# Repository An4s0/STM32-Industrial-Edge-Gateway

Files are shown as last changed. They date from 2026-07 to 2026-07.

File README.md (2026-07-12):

# STM32 Industrial Edge Gateway

**An Ethernet-Based Environmental Monitoring System for Kunak AIR
Sensors**

An embedded industrial edge gateway built on the **STM32F767ZI** that
acquires environmental measurements from a **Kunak AIR** sensor using
**Modbus RTU over RS485**, processes the collected data, calculates the
**US Air Quality Index (AQI)**, stores historical records on an SD card,
and serves a real-time web dashboard over Ethernet.

The system operates entirely on a local network without requiring cloud
services, external APIs, or internet connectivity, making it suitable
for industrial monitoring and edge computing applications.

------------------------------------------------------------------------

# Features

-   Real-time environmental monitoring
-   Modbus RTU Master implementation over RS485
-   Ethernet-based embedded web server (LwIP HTTPD)
-   Dynamic web pages using SSI (Server Side Includes)
-   Local data logging to SD card (FATFS)
-   CSV export for historical measurements
-   US Air Quality Index (AQI) calculation
-   Live browser-based dashboard
-   Bilingual user interface (English / Arabic)
-   Automatic language switching
-   Sensor communication monitoring
-   Industrial status indication using LEDs
-   Fully offline operation (No Cloud Required)

------------------------------------------------------------------------

# System Architecture

``` text
                  +----------------------+
                  |      Kunak AIR       |
                  | Environmental Sensor |
                  +----------+-----------+
                             |
                     Modbus RTU (RS485)
                             |
                STM32 Industrial Edge Gateway
                             |
        +--------------------+--------------------+
        |                                         |
   SD Card Logging                       Embedded Web Server
        |                                         |
      FATFS                                  LwIP HTTPD
        |                                         |
        +--------------------+--------------------+
                             |
                      Ethernet Network
                             |
                     Web Browser Dashboard
```

------------------------------------------------------------------------

# System Workflow

1.  Poll the Kunak AIR sensor every **10 seconds** using Modbus RTU.
2.  Read environmental measurements.
3.  Convert raw register values into engineering units.
4.  Calculate the US AQI from PM2.5 and PM10.
5.  Store measurements on the SD card as CSV records.
6.  Update the embedded web dashboard.
7.  Serve the dashboard over the local Ethernet network.

------------------------------------------------------------------------

# Measured Parameters

-   Temperature
-   Humidity
-   Pressure
-   PM1
-   PM2.5
-   PM10
-   US AQI

------------------------------------------------------------------------

# Dashboard Features

-   Real-time environmental data
-   AQI visualization
-   Automatic data refresh
-   Local Ethernet access
-   Responsive design
-   English and Arabic interface
-   AQI status indication using EPA color categories

------------------------------------------------------------------------

# Data Logging

Example CSV record:

``` text
Timestamp,Temperature,Humidity,Pressure,PM1,PM2.5,PM10,AQI
2026-06-14 12:00:00,31.20,46.00,1012.0,12.5,18.3,25.7,72
```

------------------------------------------------------------------------

# Reliability Features

-   Modbus CRC16 verification
-   Communication timeout detection
-   Sensor offline monitoring
-   Runtime status indication using LEDs
-   Watchdog-based recovery support
-   Local data storage without internet dependency

------------------------------------------------------------------------

# Technologies Used

-   Embedded Systems
-   Industrial IoT (IIoT)
-   Edge Computing
-   STM32
-   Modbus RTU
-   RS485
-   Ethernet
-   LwIP
-   FATFS
-   Embedded Web Server
-   Data Logging

------------------------------------------------------------------------

<br/>

**Keep building. Keep learning.**

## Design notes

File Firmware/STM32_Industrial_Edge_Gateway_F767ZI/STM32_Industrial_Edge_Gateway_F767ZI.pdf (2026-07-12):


06/07/2026

Industrial_Edge_Monitoring_System Project Configuration Report

## 1. Description

### 1.1. Project

Project Name | Industrial_Edge_Monitoring_System
Board Name | NUCLEO-F767ZI
Generated with: | STM32CubeMX 6.18.0
Date | 07/06/2026

### 1.2. MCU

MCU Series | STM32F7
MCU Line | STM32F7x7
MCU name | STM32F767ZITx
MCU Package | LQFP144
MCU Pin number | 144

### 1.3. Core(s) information

Core(s) | Arm Cortex-M7
1.4. Caution

The report was generated although the configuration was in a modified state. It may be not accurate

## 2. Pinout Configuration

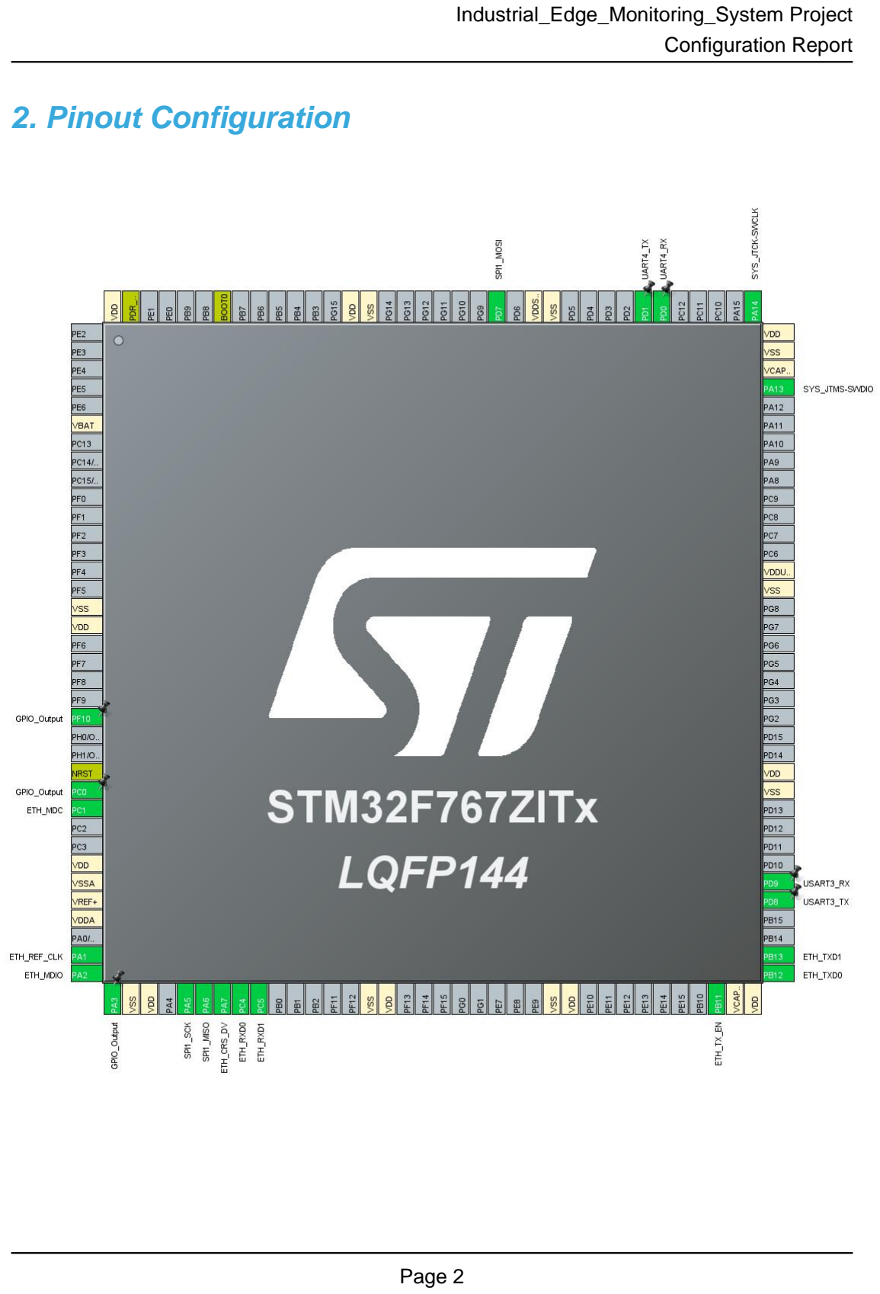
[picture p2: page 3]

## 3. Pins Configuration

Pin Number LQFP144 | Pin Name (function after reset) | Pin Type | Alternate Function(s) | Label
6 | VBAT | Power
16 | VSS | Power
17 | VDD | Power
22 | PF10 * | I/O | GPIO_Output
25 | NRST | Reset
26 | PC0 * | I/O | GPIO_Output
27 | PC1 | I/O | ETH_MDC
30 | VDD | Power
31 | VSSA | Power
32 | VREF+ | Power
33 | VDDA | Power
35 | PA1 | I/O | ETH_REF_CLK
36 | PA2 | I/O | ETH_MDIO
37 | PA3 * | I/O | GPIO_Output
38 | VSS | Power
39 | VDD | Power
41 | PA5 | I/O | SPI1_SCK
42 | PA6 | I/O | SPI1_MISO
43 | PA7 | I/O | ETH_CRS_DV
44 | PC4 | I/O | ETH_RXD0
45 | PC5 | I/O | ETH_RXD1
51 | VSS | Power
52 | VDD | Power
61 | VSS | Power
62 | VDD | Power
70 | PB11 | I/O | ETH_TX_EN
71 | VCAP_1 | Power
72 | VDD | Power
73 | PB12 | I/O | ETH_TXD0
74 | PB13 | I/O | ETH_TXD1
77 | PD8 | I/O | USART3_TX
78 | PD9 | I/O | USART3_RX
83 | VSS | Power
84 | VDD | Power
94 | VSS | Power
95 | VDDUSB | Power

Pin Number LQFP144 | Pin Name (function after reset) | Pin Type | Alternate Function(s) | Label
105 | PA13 | I/O | SYS_JTMS-SWDIO
106 | VCAP_2 | Power
107 | VSS | Power
108 | VDD | Power
109 | PA14 | I/O | SYS_JTCK-SWCLK
114 | PD0 | I/O | UART4_RX
115 | PD1 | I/O | UART4_TX
120 | VSS | Power
121 | VDDSDMMC | Power
123 | PD7 | I/O | SPI1_MOSI
130 | VSS | Power
131 | VDD | Power
138 | BOOT0 | Boot
143 | PDR_ON | Reset
144 | VDD | Power

* The pin is affected with an I/O function

## 4. Clock Tree Configuration

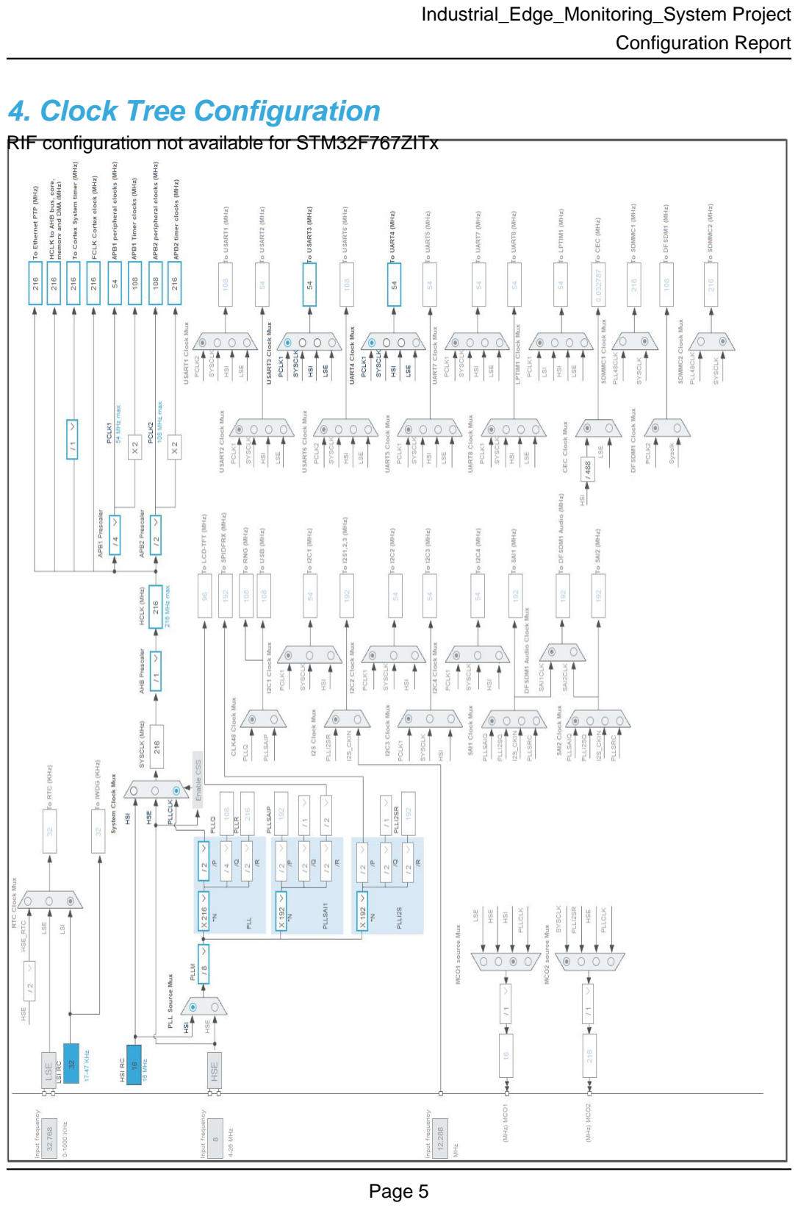
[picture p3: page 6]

RIF configuration not available for STM32F767ZITx

## 1. Power Consumption Calculator report

### 1.1. Microcontroller Selection

Series | STM32F7
Line | STM32F7x7
MCU | STM32F767ZITx
Datasheet | DS11532_Rev4

### 1.2. Parameter Selection

Temperature | 25
Vdd | 3.3

### 1.3. Battery Selection

Battery | Alkaline(9V)
Capacity | 625.0 mAh
Self Discharge | 0.3 %/month
Nominal Voltage | 9.0 V
Max Cont Current | 200.0 mA
Max Pulse Current | 0.0 mA
Cells in series | 1
Cells in parallel | 1

### 1.4. Sequence

Step | Step1 | Step2
Mode | RUN | STOP_UDM (Under Drive)
Vdd | 3.3 | 3.3
Voltage Source | Battery | Battery
Range | Scale1-High | No Scale
Fetch Type | ICTM FLASH-SingleBank REGON | n/a
CPU Frequency | 216 MHz | 0 Hz
Clock Configuration | HSE PLL | Regulator_LP Flash-PwrDwn
Clock Source Frequency | 4 MHz | 0 Hz
Peripherals
Additional Cons. | 0 mA | 0 mA
Average Current | 118 mA | 130 µA
Duration | 0.1 ms | 0.9 ms
DMIPS | 462.0 | 0.0
Ta Max | 89.42 | 104.98
Category | In DS Table | In DS Table

### 1.5. Results

Sequence Time | 1 ms | Average Current | 11.92 mA
Battery Life | 2 days, 4 hours | Average DMIPS | 462.24005 DMIPS

### 1.6. Chart

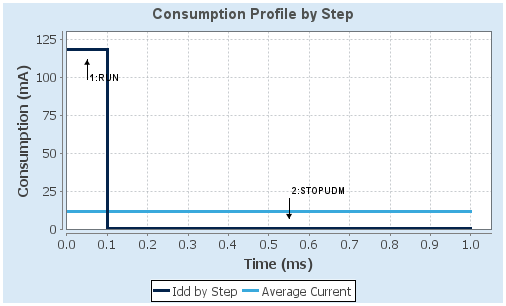
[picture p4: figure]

## 2. Software Project

### 2.1. Project Settings

Name | Value
Project Name | Industrial_Edge_Monitoring_System
Project Folder | D:\Industrial_Edge_Monitoring_System
Toolchain / IDE | CMake
Firmware Package Name and Version | STM32Cube FW_F7 V1.17.4
Application Structure | Advanced
Generate Under Root | No
Do not generate the main() | No
Minimum Heap Size | 0x200
Minimum Stack Size | 0x400

### 2.2. Code Generation Settings

Name | Value
STM32Cube MCU packages and embedded software | Copy only the necessary library files
Generate peripheral initialization as a pair of '.c/.h' files | No
Backup previously generated files when re-generating | No
Keep User Code when re-generating | Yes
Delete previously generated files when not re-generated | Yes
Set all free pins as analog (to optimize the power consumption) | No
Enable Full Assert | No

### 2.3. Advanced Settings - Generated Function Calls

Rank | Function Name | Peripheral Instance Name
1 | SystemClock_Config | RCC
2 | MX_GPIO_Init | GPIO
3 | MX_UART4_Init | UART4
4 | MX_USART3_UART_Init | USART3
5 | MX_SPI1_Init | SPI1
6 | MX_FATFS_Init | FATFS
7 | MX_ETH_Init | ETH

## 3. Peripherals and Middlewares Configuration

### 3.1. CORTEX_M7

3.1.1. Parameter Settings:

Speculation default mode Settings:

Speculation default mode | Enabled *
Cortex Interface Settings:
Flash Interface | AXI Interface
ART ACCELERATOR | Disabled
Instruction Prefetch | Disabled
CPU ICache | Disabled
CPU DCache | Disabled
Cortex Memory Protection Unit Control Settings:
MPU Control Mode | Background Region Privileged accesses only + MPU Disabled during hard fault, NMI and FAULTMASK handlers

Cortex Memory Protection Unit Region 0 Settings:

MPU Region | Enabled
MPU Region Base Address | 0x0 *
MPU Region Size | 4GB
MPU SubRegion Disable | 0x87 *
MPU TEX field level | level 0
MPU Access Permission | ALL ACCESS NOT PERMITTED
MPU Instruction Access | DISABLE
MPU Shareability Permission | ENABLE
MPU Cacheable Permission | DISABLE
MPU Bufferable Permission | DISABLE
Cortex Memory Protection Unit Region 1 Settings:
MPU Region | Disabled
Cortex Memory Protection Unit Region 2 Settings:
MPU Region | Disabled
Cortex Memory Protection Unit Region 3 Settings:
MPU Region | Disabled
Cortex Memory Protection Unit Region 4 Settings:
MPU Region | Disabled
Cortex Memory Protection Unit Region 5 Settings:
MPU Region | Disabled
Cortex Memory Protection Unit Region 6 Settings:
MPU Region | Disabled
Cortex Memory Protection Unit Region 7 Settings:

MPU Region | Disabled

### 3.2. ETH

Mode: RMII
3.2.1. Parameter Settings:

General : Ethernet Configuration:

Ethernet MAC Address | 00:80:E1:00:00:00
Tx Descriptor Length | 4
First Tx Descriptor Address | 0x2007c0a0 *
Rx Descriptor Length | 4
First Rx Descriptor Address | 0x2007c000 *
Rx Buffers Length | 1524
Rx Mode | Polling Mode

### 3.3. RCC

3.3.1. Parameter Settings:

System Parameters:

VDD voltage (V) | 3.3
Flash Latency(WS) | 7 WS (8 CPU cycle)
RCC Parameters:
HSI Calibration Value | 16
TIM Prescaler Selection | Disabled
HSE Startup Timout Value (ms) | 100
LSE Startup Timout Value (ms) | 5000
Power Parameters:
Power Over Drive | Enabled
Power Regulator Voltage Scale | Power Regulator Voltage Scale 1

### 3.4. SPI1

Mode: Full-Duplex Master
3.4.1. Parameter Settings:

Basic Parameters:

Frame Format | Motorola
Data Size | 8 Bits *
First Bit | MSB First
Clock Parameters:
Prescaler (for Baud Rate) | 256 *
Baud Rate | 421.875 KBits/s *
Clock Polarity (CPOL) | Low
Clock Phase (CPHA) | 1 Edge
Advanced Parameters:
CRC Calculation | Disabled
NSSP Mode | Enabled
NSS Signal Type | Software

### 3.5. SYS

Debug: Serial Wire
Timebase Source: SysTick

### 3.6. UART4

Mode: Asynchronous
3.6.1. Parameter Settings:

Basic Parameters:

Baud Rate | 19200 *
Word Length | 8 Bits (including Parity)
Parity | None
Stop Bits | 1
Advanced Parameters:
Data Direction | Receive and Transmit
Over Sampling | 16 Samples
Single Sample | Disable
Advanced Features:
Auto Baudrate | Disable
TX Pin Active Level Inversion | Disable
RX Pin Active Level Inversion | Disable
Data Inversion | Disable
TX and RX Pins Swapping | Disable
Overrun | Enable
DMA on RX Error | Enable

MSB First | Disable

### 3.7. USART3

Mode: Asynchronous
3.7.1. Parameter Settings:

Basic Parameters:

Baud Rate | 115200
Word Length | 8 Bits (including Parity)
Parity | None
Stop Bits | 1
Advanced Parameters:
Data Direction | Receive and Transmit
Over Sampling | 16 Samples
Single Sample | Disable
Advanced Features:
Auto Baudrate | Disable
TX Pin Active Level Inversion | Disable
RX Pin Active Level Inversion | Disable
Data Inversion | Disable
TX and RX Pins Swapping | Disable
Overrun | Enable
DMA on RX Error | Enable
MSB First | Disable

### 3.8. FATFS

mode: User-defined
3.8.1. Set Defines:

Version:

FATFS version | R0.12c
Function Parameters:
FS_READONLY (Read-only mode) | Disabled
FS_MINIMIZE (Minimization level) | Disabled
USE_STRFUNC (String functions) | Enabled with LF -> CRLF conversion
USE_FIND (Find functions) | Disabled
USE_MKFS (Make filesystem function) | Enabled
USE_FASTSEEK (Fast seek function) | Enabled

USE_EXPAND (Use f_expand function) | Disabled
USE_CHMOD (Change attributes function) | Disabled
USE_LABEL (Volume label functions) | Disabled
USE_FORWARD (Forward function) | Disabled
Locale and Namespace Parameters:
CODE_PAGE (Code page on target) | Latin 1
USE_LFN (Use Long Filename) | Disabled
MAX_LFN (Max Long Filename) | 255
LFN_UNICODE (Enable Unicode) | ANSI/OEM
STRF_ENCODE (Character encoding) | UTF-8
FS_RPATH (Relative Path) | Disabled
Physical Drive Parameters:
VOLUMES (Logical drives) | 1
MAX_SS (Maximum Sector Size) | 512
MIN_SS (Minimum Sector Size) | 512
MULTI_PARTITION (Volume partitions feature) | Disabled
USE_TRIM (Erase feature) | Disabled
FS_NOFSINFO (Force full FAT scan) | 0
System Parameters:
FS_TINY (Tiny mode) | Disabled
FS_EXFAT (Support of exFAT file system) | Disabled
FS_NORTC (Timestamp feature) | Dynamic timestamp
FS_REENTRANT (Re-Entrancy) | Disabled
FS_TIMEOUT (Timeout ticks) | 1000
FS_LOCK (Number of files opened simultaneously) | 2

* User modified value

## 4. System Configuration

### 4.1. GPIO configuration

IP | Pin | Signal | GPIO mode | GPIO pull/up pull down | Max Speed | User Label
ETH | PC1 | ETH_MDC | Alternate Function Push Pull | No pull-up and no pull-down | High
| PA1 | ETH_REF_CLK | Alternate Function Push Pull | No pull-up and no pull-down | High
| PA2 | ETH_MDIO | Alternate Function Push Pull | No pull-up and no pull-down | High
| PA7 | ETH_CRS_DV | Alternate Function Push Pull | No pull-up and no pull-down | High
| PC4 | ETH_RXD0 | Alternate Function Push Pull | No pull-up and no pull-down | High
| PC5 | ETH_RXD1 | Alternate Function Push Pull | No pull-up and no pull-down | High
| PB11 | ETH_TX_EN | Alternate Function Push Pull | No pull-up and no pull-down | High
| PB12 | ETH_TXD0 | Alternate Function Push Pull | No pull-up and no pull-down | High
| PB13 | ETH_TXD1 | Alternate Function Push Pull | No pull-up and no pull-down | High
SPI1 | PA5 | SPI1_SCK | Alternate Function Push Pull | No pull-up and no pull-down | Very High *
| PA6 | SPI1_MISO | Alternate Function Push Pull | No pull-up and no pull-down | Very High *
| PD7 | SPI1_MOSI | Alternate Function Push Pull | No pull-up and no pull-down | Very High *
SYS | PA13 | SYS_JTMS-SWDIO | n/a | n/a | n/a
| PA14 | SYS_JTCK-SWCLK | n/a | n/a | n/a
UART4 | PD0 | UART4_RX | Alternate Function Push Pull | No pull-up and no pull-down | Very High *
| PD1 | UART4_TX | Alternate Function Push Pull | No pull-up and no pull-down | Very High *
USART3 | PD8 | USART3_TX | Alternate Function Push Pull | No pull-up and no pull-down | Very High *
| PD9 | USART3_RX | Alternate Function Push Pull | No pull-up and no pull-down | Very High *
GPIO | PF10 | GPIO_Output | Output Push Pull | No pull-up and no pull-down | Low
| PC0 | GPIO_Output | Output Push Pull | No pull-up and no pull-down | Low
| PA3 | GPIO_Output | Output Push Pull | No pull-up and no pull-down | Low

### 4.2. DMA configuration

nothing configured in DMA service

### 4.3. NVIC configuration

4.3.1. NVIC
Interrupt Table | Enable | Preenmption Priority | SubPriority
Non maskable interrupt | true | 0 | 0
Hard fault interrupt | true | 0 | 0
Memory management fault | true | 0 | 0
Pre-fetch fault, memory access fault | true | 0 | 0
Undefined instruction or illegal state | true | 0 | 0
System service call via SWI instruction | true | 0 | 0
Debug monitor | true | 0 | 0
Pendable request for system service | true | 0 | 0
System tick timer | true | 0 | 0
PVD interrupt through EXTI line 16 | unused
Flash global interrupt | unused
RCC global interrupt | unused
SPI1 global interrupt | unused
USART3 global interrupt | unused
UART4 global interrupt | unused
Ethernet global interrupt | unused
Ethernet wake-up interrupt through EXTI line 19 | unused
FPU global interrupt | unused
4.3.2. NVIC Code generation
Enabled interrupt Table | Select for init sequence ordering | Generate IRQ handler | Call HAL handler
Non maskable interrupt | false | true | false
Hard fault interrupt | false | true | false
Memory management fault | false | true | false
Pre-fetch fault, memory access fault | false | true | false
Undefined instruction or illegal state | false | true | false
System service call via SWI instruction | false | true | false
Debug monitor | false | true | false
Pendable request for system service | false | true | false
System tick timer | false | true | true

* User modified value

## 5. System Views

5.1. Category view
5.1.1. Current

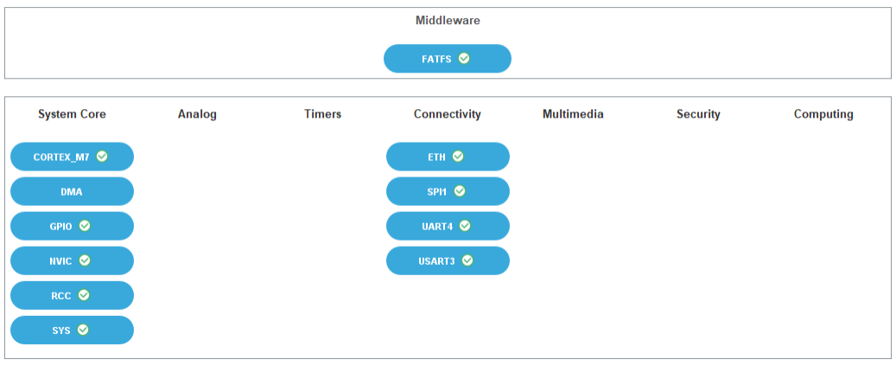
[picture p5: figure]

## 6. Docs & Resources

Type | Link
BSDL files | https://www.st.com/resource/en/bsdl_model/stm32f7_bsdl.zip
IBIS models | https://www.st.com/resource/en/ibis_model/stm32f7_ibis.zip
System View Description | https://www.st.com/resource/en/svd/stm32f7-svd.zip
Presentations | https://www.st.com/resource/en/product_presentation/stm32-stm8_embedded_software_solutions.pdf
Presentations | https://www.st.com/resource/en/product_presentation/stm32_eval-tools_portfolio.pdf
Presentations | https://www.st.com/resource/en/product_presentation/stm32_stm8_functi onal-safety-packages.pdf
Presentations | https://www.st.com/resource/en/product_presentation/stm32-stm8_software_development_tools.pdf
Presentations | https://www.st.com/resource/en/product_presentation/microcontrollers-stm32-family-overview.pdf
Flyers | https://www.st.com/resource/en/flyer/flstm32nucleo.pdf
Flyers | https://www.st.com/resource/en/flyer/flstm32trust.pdf
Security Bulletin | https://www.st.com/resource/en/technical_note/tn1489-security-bulletin-tn1489stpsirt-physical-attacks-on-stm32-and-stm32cube-firmware-stmicroelectronics.pdf
Application Notes | https://www.st.com/resource/en/application_note/an1709-emc-design-guide-for-stm8-stm32-and-legacy-mcus-stmicroelectronics.pdf
Application Notes | https://www.st.com/resource/en/application_note/an4031-using-the-stm32f2-stm32f4-and-stm32f7-series-dma-controller-stmicroelectronics.pdf
Application Notes | https://www.st.com/resource/en/application_note/an4221-i2c-protocol-used-in-the-stm32-bootloader-stmicroelectronics.pdf
Application Notes | https://www.st.com/resource/en/application_note/an4655-virtually-increasing-the-number-of-serial-communication-peripherals-in-stm32-applications-stmicroelectronics.p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

Application Notes | https://www.st.com/resource/en/application_note/an4661-getting-started-with-stm32f7-series-mcu-hardware-development-stmicroelectronics.pdf
Application Notes | https://www.st.com/resource/en/application_note/an4676-stm32f7-series-peripheral-interconnections-stmicroelectronics.pdf
Application Notes | https://www.st.com/resource/en/application_note/an4731-stm32cube-mcu-package-examples-for-stm32f7-series-stmicroelectronics.pdf
Application Notes | https://www.st.com/resource/en/application_note/an4750-handling-of-soft-errors-in-stm32-applications-stmicroelectronics.pdf
Application Notes | https://www.st.com/resource/en/application_note/an4803-highspeed-si-simulations-using-ibis-and-boardlevel-simulations-using-hyperlynx-si-on-stm32-mcus-and-mpus-stmic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
Application Notes | https://www.st.com/resource/en/application_note/an4839-level-1-cache-on-stm32f7-series-and-stm32h7-series-stmicroelectronics.pdf
Application Notes | https://www.st.com/resource/en/application_note/an4850-stm32-mcus-spreadspectrum-clock-generation-principles-properties-and-implementation-stmicroelectronics.pdf
Application Notes | https://www.st.com/resource/en/application_note/an4990-getting-started-with-sigmadelta-digital-interface-on-applicable-stm32-microcontrollers-stmicroelectronics.pdf
Application Notes | https://www.st.com/resource/en/application_note/an5027-interfacing-pdm-digital-microphones-using-stm32-mcus-and-mpus-stmicroelectronics.pdf
Application Notes | https://www.st.com/resource/en/application_note/an5073-receiving-spdif-audio-stream-with-the-stm32f4f7h7-series-stmicroelectronics.pdf
Application Notes | https://www.st.com/resource/en/application_note/an4899-stm32-microcontroller-gpio-hardware-settings-and-lowpower-consumption-stmicroelectronics.pdf
Application Notes | https://www.st.com/resource/en/application_note/an5612-esd-protection-of-stm32-mcus-and-mpus-stmicroelectronics.pdf
Application Notes | https://www.st.com/resource/en/application_note/an5293-migration-guide-from-stm32f7-series-to-stmh74x75x-stm32h72x73x-and-stmh7a37bx-devices-stmicroelectronics.pdf
Application Notes | https://www.st.com/resource/en/application_note/an4838-introduction-to- memory-protection-unit-management-on-stm32-mcus-

| stmicroelectronics.pdf
Application Notes | https://www.st.com/resource/en/application_note/an4879-introduction-to-usb-hardware-and-pcb-guidelines-using-stm32-mcus-stmicroelectronics.pdf
Application Notes | https://www.st.com/resource/en/application_note/an5225-introduction-to-usb-typec-power-delivery-for-stm32-mcus-and-mpus-stmicroelectronics.pdf
Application Notes | https://www.st.com/resource/en/application_note/an5537-how-to-use-adc-oversampling-techniques-to-improve-signaltonoise-ratio-on-stm32-mcus-stmicroelectronics.pdf
Application Notes | https://www.st.com/resource/en/application_note/an4230-introduction-to-random-number-generation-validation-using-the-nist-statistical-test-suite-for-stm32-mcus-and-m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
Application Notes | https://www.st.com/resource/en/application_note/an2867-guidelines-for-oscillator-design-on-stm8afals-and-stm32-mcusmpus-stmicroelectronics.pdf
Application Notes | https://www.st.com/resource/en/application_note/an4013-introduction-to-timers-for-stm32-mcus-stmicroelectronics.pdf
Application Notes | https://www.st.com/resource/en/application_note/an4277-how-to-use-pwm-shutdown-for-motor-control-and-digital-power-conversion-on-stm32-mcus-stmicroelectronics.pdf
Application Notes | https://www.st.com/resource/en/application_note/an4861-introduction-to-lcdtft-display-controller-ltdc-on-stm32-mcus-stmicroelectronics.pdf
Application Notes | https://www.st.com/resource/en/application_note/an4908-getting-started-with-usart-automatic-baud-rater-detection-for-stm32-mcus-stmicroelectronics.pdf
Application Notes | https://www.st.com/resource/en/application_note/an5156-introduction-to-security-for-stm32-mcus-stmicroelectronics.pdf
Application Notes | https://www.st.com/resource/en/application_note/an5543-guidelines-for-enhanced-spi-communication-on-stm32-mcus-and-mpus-stmicroelectronics.pdf
Application Notes | https://www.st.com/resource/en/application_note/cd00211314-how-to-optimize-the-adc-accuracy-in-the-stm32-mcus-stmicroelectronics.pdf

Application Notes | https://www.st.com/resource/en/application_note/an2639-soldering-recommendations-and-package-information-for-leadfree-ecopack2-mcus-and-mpus-stmicroelectronics.pdf
Application Notes | https://www.st.com/resource/en/application_note/an5020-introduction-to-digital-camera-interface-dcmi-for-stm32-mcus-stmicroelectronics.pdf
Application Notes | https://www.st.com/resource/en/application_note/an3154-how-to-use-can-protocol-in-bootloader-on-stm32-mcus-stmicroelectronics.pdf
Application Notes | https://www.st.com/resource/en/application_note/an4566-how-to-extend-the-dac-performance-on-stm32-mcus-stmicroelectronics.pdf
Application Notes | https://www.st.com/resource/en/application_note/an5647-the-goertzel-algorithm-to-compute-individual-terms-of-the-discrete-fourier-transform-dft-in-stm32-products-stm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
Application Notes | https://www.st.com/resource/en/application_note/an2606-introduction-to-system-memory-boot-mode-on-stm32-mcus-stmicroelectronics.pdf
Application Notes | https://www.st.com/resource/en/application_note/an5036-guidelines-for-thermal-management-on-stm32-mcus-and-mpus-stmicroelectronics.pdf
Application Notes | https://www.st.com/resource/en/application_note/an3126-how-to-use-dac-for-audio-and-waveform-generation-on-stm32-mcus-and-mpus-stmicroelectronics.pdf
Application Notes | https://www.st.com/resource/en/application_note/an3155-how-to-use-usart-protocol-in-bootloader-on-stm32-mcus-stmicroelectronics.pdf
Application Notes | https://www.st.com/resource/en/application_note/an3156-how-to-use-usb-dfu-protocol-in-bootloader-on-stm32-mcus-stmicroelectronics.pdf
Application Notes | https://www.st.com/resource/en/application_note/an4286-how-to-use-spi-protocol-in-bootloader-on-stm32-mcus-stmicroelectronics.pdf
Application Notes | https://www.st.com/resource/en/application_note/an4759-introduction-to-using-the-hardware-realtime-clock-rtc-and-the-tamper-management-unit-tamp-for-stm32-mcus-stmic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
Application Notes | https://www.st.com/resource/en/application_note/an4760-introduction-to-quadspi-interface-for-stm32-mcus-and-mpus-stmicroelectronics.pdf
Application Notes | https://www.st.com/resource/en/application_note/an4776-how-to-use-generalpurpose-timer-peripheral-on-stm32-mcus-stmicroelectronics.pdf
Application Notes | https://www.st.com/resource/en/application_note/an4936-migrating-

| applications-from-stm32f7-to-stm32h743h753-mcus-stmicroelectronics.pdf
Application Notes | https://www.st.com/resource/en/application_note/an4989-introduction-to-debug-toolbox-for-stm32-mcus-stmicroelectronics.pdf
Application Notes | https://www.st.com/resource/en/application_note/an4660-migrating-from-stm32f42xxx43xxx-to-stm32f7-mcus-stmicroelectronics.pdf
Design Notes & Tips | https://www.st.com/resource/en/design_tip/dt0117-microphone-array-beamforming-in-the-pcm-and-pdm-domain-stmicroelectronics.pdf
Errata Sheets | https://www.st.com/resource/en/errata_sheet/es0334-stm32f76xxx-and-stm32f77xxx-device-errata-stmicroelectronics.pdf
Datasheet | https://www.st.com/resource/en/datasheet/dm00273119.pdf
Programming Manuals | https://www.st.com/resource/en/programming_manual/pm0253-stm32f7-series-and-stm32h7-series-cortexm7-processor-programming-manual-stmicroelectronics.pdf
Reference Manuals | https://www.st.com/resource/en/reference_manual/rm0410-stm32f76xxx-and-stm32f77xxx-advanced-armbased-32bit-mcus-stmicroelectronics.pdf
Technical Notes & Articles | https://www.st.com/resource/en/technical_note/tn1163-description-of-wlcsp-for-microcontrollers-and-recommendations-for-its-use-stmicroelectronics.pdf
Technical Notes & Articles | https://www.st.com/resource/en/technical_note/tn1205-tape-and-reel-shipping-media-for-stm8-and-stm32-microcontrollers-in-fpn-packages-stmicroelectronics.pdf
Technical Notes & Articles | https://www.st.com/resource/en/technical_note/tn1206-tape-and-reel-shipping-media-for-stm8-and-stm32-microcontrollers-in-qfp-packages-stmicroelectronics.pdf
Technical Notes & Articles | https://www.st.com/resource/en/technical_note/tn1207-tape-and-reel-shipping-media-for-stm8-and-stm32-microcontrollers-in-so-packages-stmicroelectronics.pdf
Technical Notes & Articles | https://www.st.com/resource/en/technical_note/tn1208-tape-and-reel-shipping-media-for-stm8-and-stm32-microcontrollers-in-tssop-and-ssop-packages-stmicroelectronics.p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

Technical Notes
& Articles

https://www.st.com/resource/en/technical_note/tn1433-reference-devicemarking-schematics-for-stm32-microcontrollers-and-microprocessors-

| stmicroelectronics.pdf
Technical Notes & Articles | https://www.st.com/resource/en/technical_note/tn1204-tape-and-reel-shipping-media-for-stm32-devices-in-bga-packages-stmicroelectronics.pdf
User Manuals | https://www.st.com/resource/en/user_manual/um2318-stm32f7-series-safety-manual-stmicroelectronics.pdf
User Manuals | https://www.st.com/resource/en/user_manual/um3251-stm32f7-series-ulcsaiec-607301603351-selftest-library-user-guide-stmicroelectronics.pdf

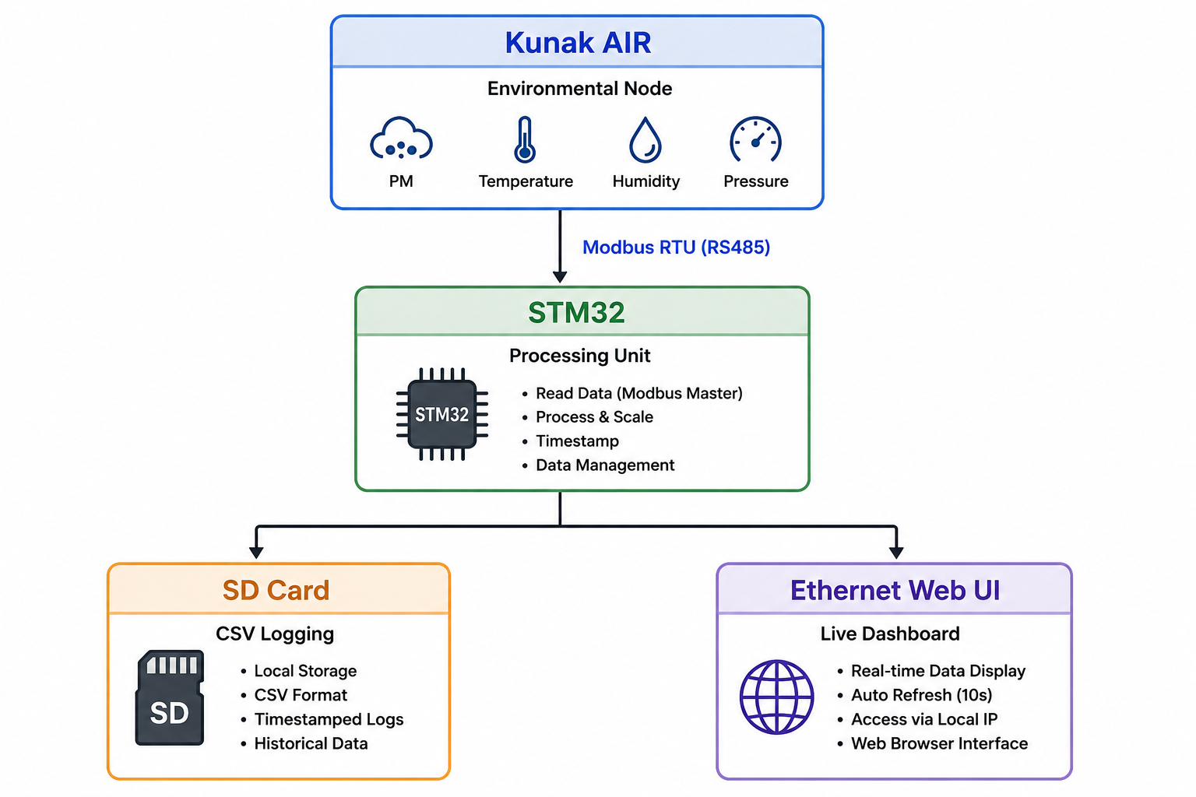
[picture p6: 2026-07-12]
System_Architecture.png

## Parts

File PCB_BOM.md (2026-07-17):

# STM32 Industrial Edge Gateway - PCB BOM

## 1. Power Supply

### Power Input

- DC Barrel Jack (5.5 × 2.1mm)

### Protection

- 1A Fuse
- TVS Diode: SMAJ15A
- Reverse Polarity Protection: AO3407A

### Voltage Regulation

- Buck Converter: MP2338GTL (Input → 5V)
- LDO: TLV76733DRVR (5V → 3.3V)

### Indicator

- Power LED

---

## 2. STM32 MCU Core

### Microcontroller

- STM32F407VGT6

### Clock

- HSE Crystal: SMD3225 (8MHz)
- Crystal Load Capacitors

### Power Filtering

- VDDA Ferrite Bead: BLM18AG601SN1D
- Decoupling Capacitors:
  - 100nF
  - 1uF

### Boot Configuration

- BOOT0 Jumper
- BOOT0 Pull-down Resistor

### Reset Circuit

- Reset Button
- Pull-up Resistor

### SWD Debug Interface

- SWD Header
  - 3.3V
  - SWDIO
  - SWCLK
  - NRST
  - GND

- ST-Link V2 Programmer

---

## 3. Ethernet Interface

### Ethernet PHY

- LAN8742A

### PHY Clock

- 25MHz Crystal:
  - Abracon ABM8G
- Crystal Load Capacitors

### Ethernet Connector

- RJ45 with Integrated Magnetics:
  - HanRun HR911105A

### Protection

- Ethernet TVS Protection:
  - SRV05-4

### Indicators

- Ethernet Link LED
- Ethernet Activity LED

---

## 4. RS485 / Modbus RTU

### Transceiver

- MAX3485ESA

### Connector

- 2-Pin Terminal Block
  - A
  - B

### Protection

- RS485 TVS:
  - SM712

### Bus Components

- 120Ω Termination Resistor
- Bias Resistors

### Indicator

- Modbus LED
---

## 5. microSD Storage

### Connector

- microSD Socket:
  - Hirose DM3AT

### Support Components

- Pull-up Resistors
- Decoupling Capacitor

### Indicator

- SD Activity LED

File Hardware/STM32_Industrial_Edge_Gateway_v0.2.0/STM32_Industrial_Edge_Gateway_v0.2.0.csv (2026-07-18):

Reference | Qty | Value
C1,C3,C4 | 3 | 22μF
C2,C5 | 2 | 0.1μF
C6 | 1 | 22nF
C7 | 1 | 300pF
C8,C9 | 2 | 1uF
C10,C11,C12,C13,C14,C15,C16,C17,C21,C26,C27,C28,C31,C32,C33,C35 | 16 | 100nF
C18,C30 | 2 | 1µF
C19,C20 | 2 | 2.2µF
C22,C23 | 2 | 22pF
C24,C25 | 2 | 18pF
C29 | 1 | 470pF
C34 | 1 | 10uF
D1 | 1 | SMAJ15A
D2 | 1 | SRV05-4
D3 | 1 | SM712_SOT23
D4 | 1 | POWER_LED
D5 | 1 | MODBUS_LED
D6 | 1 | SD_LED
F1 | 1 | 1A Fuse
FL1,FL2,FL3 | 3 | BLM18AG601SN1D
J1 | 1 | DC Barrel Jack (5.5 × 2.1mm)
J2 | 1 | SWD_DEBUG
J3 | 1 | BOOT0
J4 | 1 | RJ45_Hanrun_HR911105A_Horizontal
J5 | 1 | A_B
J6 | 1 | DM3AT-SF-PEJM5
J7 | 1 | TPs_USART1
J8 | 1 | TPs_RS485
J9 | 1 | TPs_SPI1
J10 | 1 | TPs_POWER
L1 | 1 | 6.8μH
Q1 | 1 | AO3407A
R1,R6 | 2 | 100k
R2 | 1 | 90.9k
R3,R7,R8,R9,R16,R17 | 6 | 10k
R4 | 1 | 191k
R5 | 1 | 49.9k
R10 | 1 | 12.1k
R11,R12,R18,R19,R20,R21,R22,R23,R24 | 9 | 330
R13,R14 | 2 | 680
R15 | 1 | 120
SW1 | 1 | SW_Push
U1 | 1 | MP2338GTL
U2 | 1 | TLV76733DRVR
U3 | 1 | STM32F407VGTx
U4 | 1 | SMD3225
U5 | 1 | LAN8742A
U6 | 1 | MAX3485ESA_T
Y1 | 1 | ABM8G-25.000MHZ-B4Y-T3

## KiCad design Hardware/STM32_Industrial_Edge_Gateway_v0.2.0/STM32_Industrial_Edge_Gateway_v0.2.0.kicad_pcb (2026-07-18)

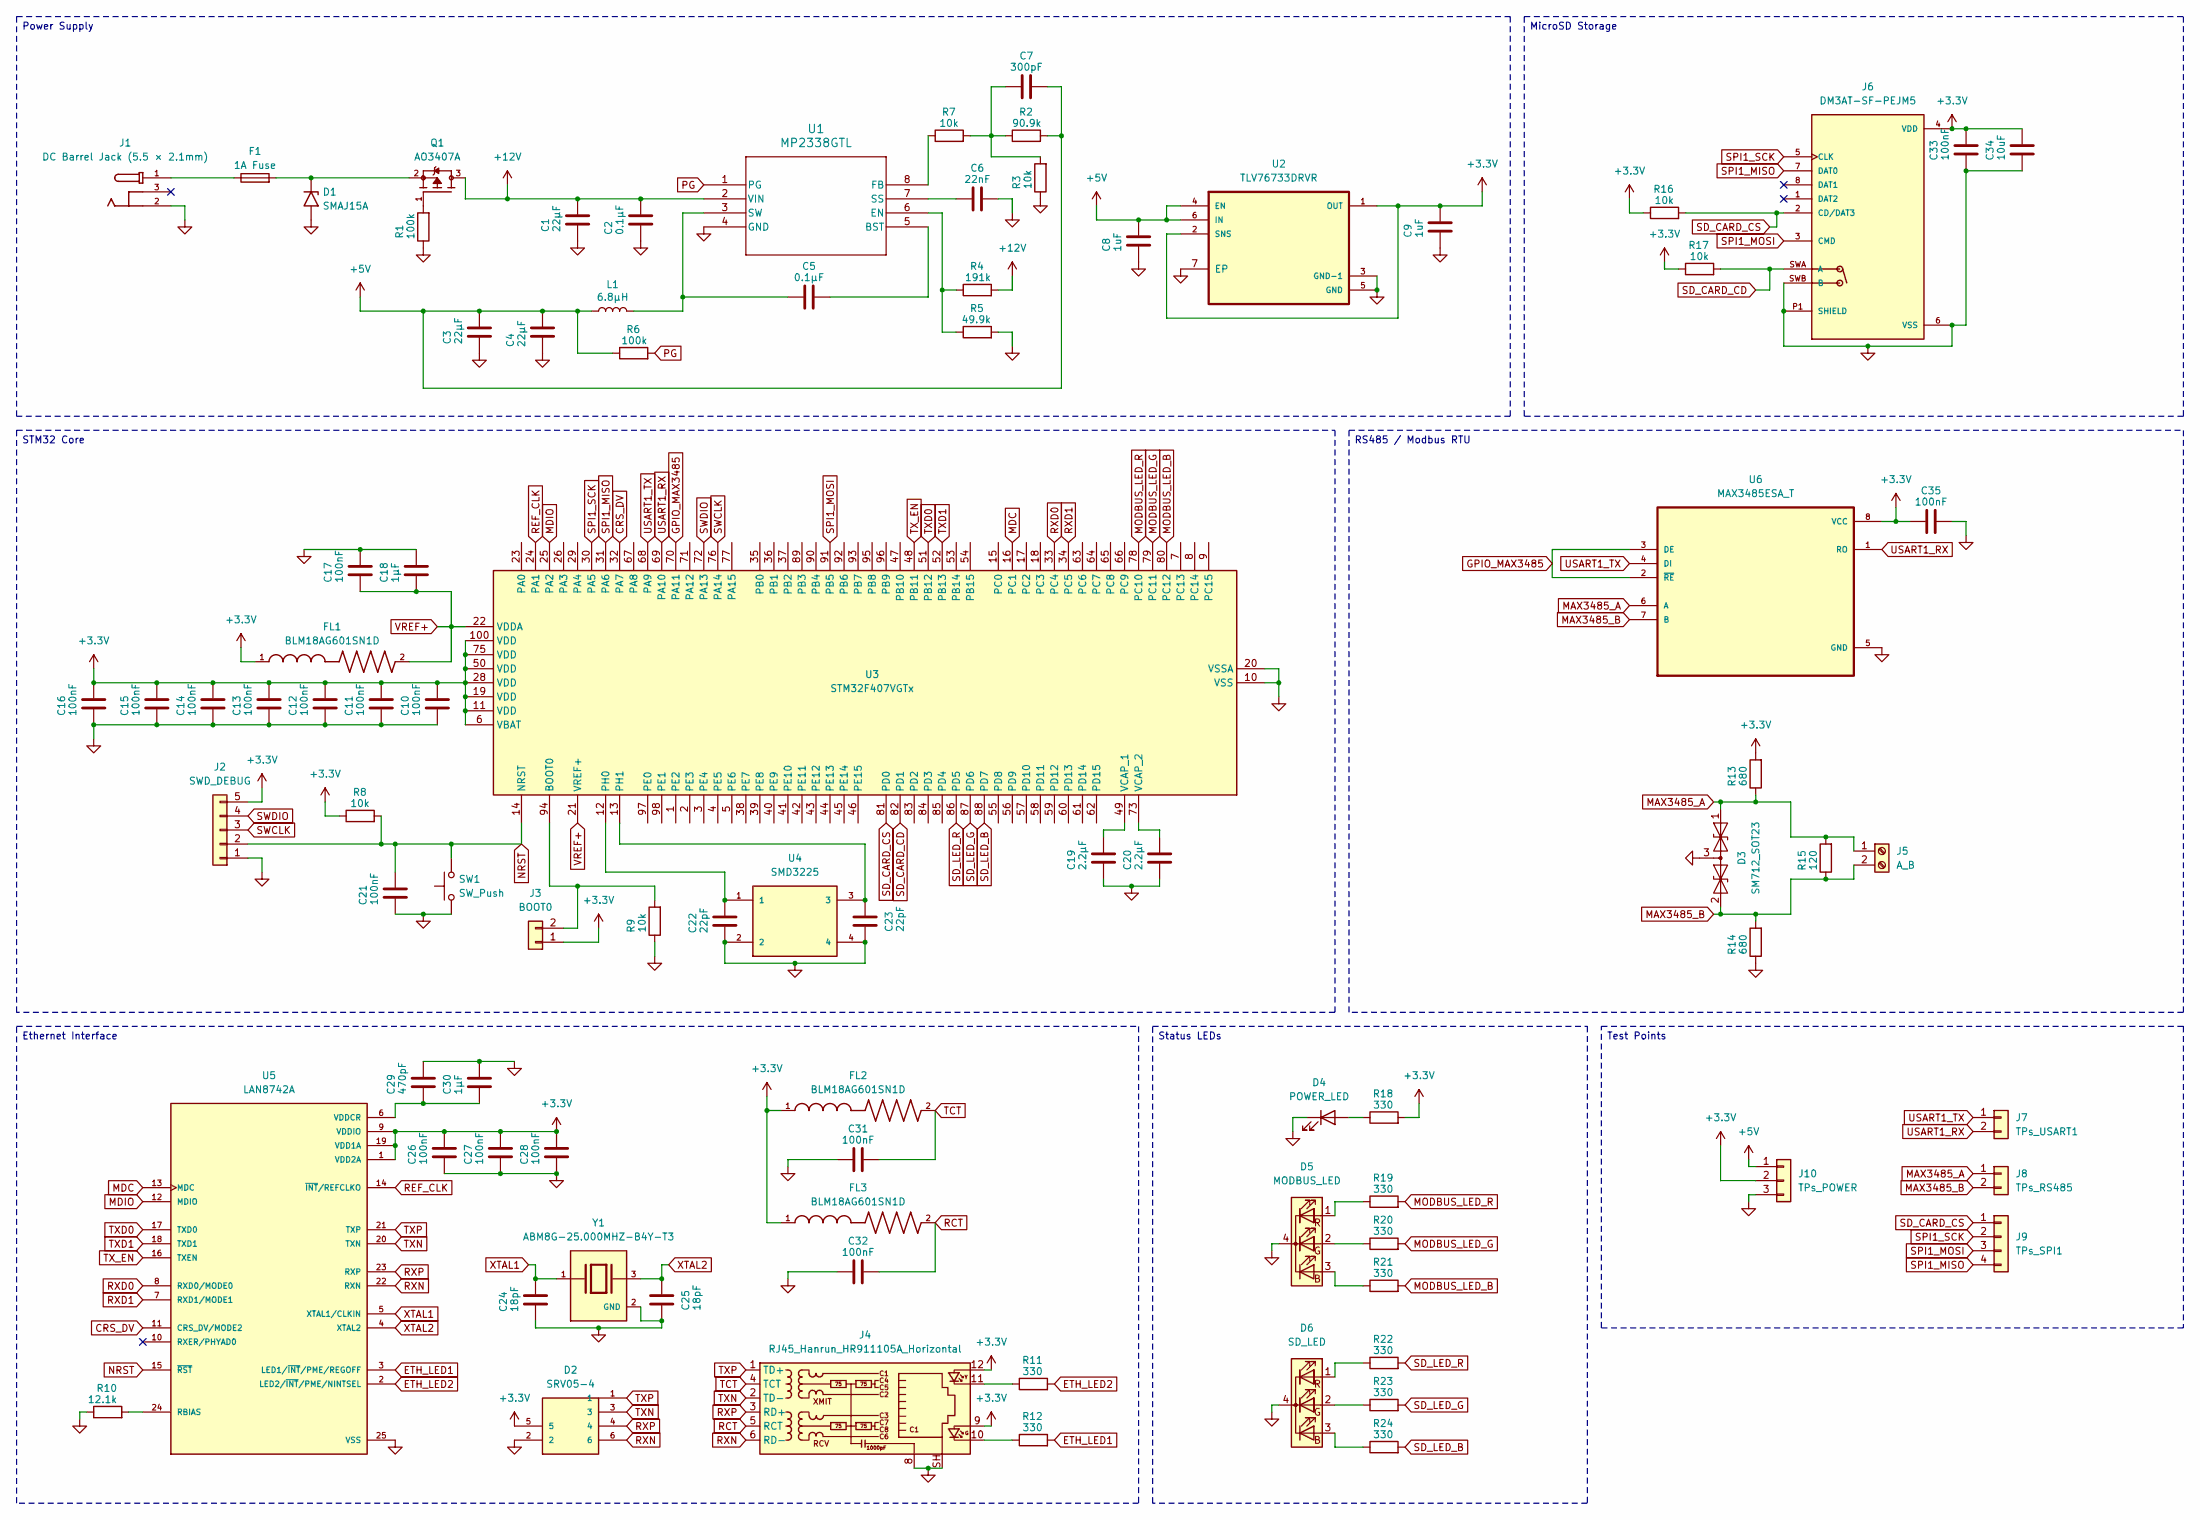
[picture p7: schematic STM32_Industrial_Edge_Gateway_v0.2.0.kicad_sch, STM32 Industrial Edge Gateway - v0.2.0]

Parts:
C1, C3, C4: 22μF; C_0603_1608Metric
C2, C5: 0.1μF; C_0603_1608Metric
C6: 22nF; C_0603_1608Metric
C7: 300pF; C_0603_1608Metric
C8, C9: 1uF; C_0603_1608Metric
C10, C11, C12, C13, C14, C15, C16, C17, C21, C26, C27, C28, C31, C32, C33, C35: 100nF; C_0603_1608Metric
C18, C30: 1µF; C_0603_1608Metric
C19, C20: 2.2µF; C_0603_1608Metric
C22, C23: 22pF; C_0603_1608Metric
C24, C25: 18pF; C_0603_1608Metric
C29: 470pF; C_0603_1608Metric
C34: 10uF; C_0603_1608Metric
D1: SMAJ15A; D_SMA
D2: SRV05-4; SOT95P280X145-6N; MOUSER_PART_NUMBER 947-SRV05-4.TCT
D3: SM712_SOT23; SOT-23
D4: POWER_LED; LED_0603_1608Metric
D5: MODBUS_LED; LED_RGB_1210
D6: SD_LED; LED_RGB_1210
F1: 1A Fuse; Fuse_1206_3216Metric
FL1, FL2, FL3: BLM18AG601SN1D; BEADC1608X95N
J1: DC Barrel Jack (5.5 × 2.1mm); EJ503A; PARTREV B
J2: SWD_DEBUG; PinHeader_1x05_P2.54mm_Vertical
J3: BOOT0; PinHeader_1x02_P2.54mm_Vertical
J4: RJ45_Hanrun_HR911105A_Horizontal
J5: A_B; TerminalBlock_Phoenix_MKDS-1,5-2-5.08_1x02_P5.08mm_Horizont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
J6: DM3AT-SF-PEJM5; HRS_DM3AT-SF-PEJM5; PARTREV 20200913
J7: TPs_USART1; PinHeader_1x02_P2.54mm_Vertical
J8: TPs_RS485; PinHeader_1x02_P2.54mm_Vertical
J9: TPs_SPI1; PinHeader_1x04_P2.54mm_Vertical
J10: TPs_POWER; PinHeader_1x03_P2.54mm_Vertical
L1: 6.8μH; L_0805_2012Metric
Q1: AO3407A; PARTREV 5
R1, R6: 100k; R_0603_1608Metric
R2: 90.9k; R_0603_1608Metric
R3, R7, R8, R9, R16, R17: 10k; R_0603_1608Metric
R4: 191k; R_0603_1608Metric
R5: 49.9k; R_0603_1608Metric
R10: 12.1k; R_0603_1608Metric
R11, R12, R18, R19, R20, R21, R22, R23, R24: 330; R_0603_1608Metric
R13, R14: 680; R_0603_1608Metric
R15: 120; R_0603_1608Metric
SW1: SW_Push; SW_SPST_TL3342
U1: MP2338GTL
U2: TLV76733DRVR; SON65P200X200X80-7N
U3: STM32F407VGTx; LQFP-100_14x14mm_P0.5mm
U4: SMD3225
U5: LAN8742A; LAN8742A-CZ-TR; PARTREV A
U6: MAX3485ESA_T; SOIC127P600X175-8N
Y1: ABM8G-25.000MHZ-B4Y-T3; XTAL_ABM8G-25.000MHZ-B4Y-T3; PARTREV 08.13.15

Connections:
+3.3V: C9.1, C10.1, C11.1, C12.1, C13.1, C14.1, C15.1, C16.1, C26.1, C27.1, C28.1, C33.1, C34.1, C35.1, D2.5, FL1.1, FL2.1, FL3.1, J2.5, J3.1, J4.9, J4.12, J6.4 (VDD), J10.2, R8.1, R13.2, R16.1, R17.1, R18.2, U2.1 (OUT), U2.2 (SNS), U3.6 (VBAT), U3.11 (VDD), U3.19 (VDD), U3.28 (VDD), U3.50 (VDD), U3.75 (VDD), U3.100 (VDD), U5.1 (VDD2A), U5.9 (VDDIO), U5.19 (VDD1A), U6.8 (VCC)
+5V: C3.1, C4.1, C7.2, C8.1, J10.1, L1.1, R2.2, R6.1, U2.4 (EN), U2.6 (IN)
+12V: C1.1, C2.1, Q1.3, R4.2, U1.2 (VIN)
CRS_DV: U3.32 (PA7), U5.11 (CRS_DV/MODE2)
ETH_LED1: R12.2, U5.3 (LED1/~INT/PME/REGOFF)
ETH_LED2: R11.2, U5.2 (LED2/~INT/PME/NINTSEL)
GND: C1.2, C2.2, C3.2, C4.2, C6.2, C8.2, C9.2, C10.2, C11.2, C12.2, C13.2, C14.2, C15.2, C16.2, C17.1, C18.1, C19.2, C20.2, C21.2, C22.2, C23.1, C24.2, C25.1, C26.2, C27.2, C28.2, C29.1, C30.1, C31.1, C32.1, C33.2, C34.2, C35.2, D1.2 (A2), D2.2, D3.3 (common), D4.1 (K), D5.4 (K), D6.4 (K), J1.2, J2.1, J4.8, J4.SH, J6.6 (VSS), J6.P1 (SHIELD), J6.P2 (SHIELD), J6.P3 (SHIELD), J6.P4 (SHIELD), J6.SWB (B), J10.3, R1.1, R3.1, R5.2, R9.1, R10.1, R14.1, SW1.1, U1.4 (GND), U2.3 (GND-1), U2.5 (GND), U2.7 (EP), U3.10 (VSS), U3.20 (VSSA), U3.27 (VSS), U3.74 (VSS), U3.99 (VSS), U4.2, U4.4, U5.25 (VSS), U6.5 (GND), Y1.2 (GND), Y1.4 (GND)
GPIO_MAX3485: U3.70 (PA11), U6.2 (~RE), U6.3 (DE)
MAX3485_A: D3.1 (A1), J5.1, J8.1, R13.1, R15.2, U6.6 (A)
MAX3485_B: D3.2 (A2), J5.2, J8.2, R14.2, R15.1, U6.7 (B)
MDC: U3.16 (PC1), U5.13 (MDC)
MDIO: U3.25 (PA2), U5.12 (MDIO)
MODBUS_LED_B: R21.2, U3.80 (PC12)
MODBUS_LED_G: R20.2, U3.79 (PC11)
MODBUS_LED_R: R19.2, U3.78 (PC10)
NRST: C21.1, J2.2, R8.2, SW1.2, U3.14 (NRST), U5.15 (~RST)
unnamed: C7.1, R2.1, R3.2, R7.2
unnamed: D1.1 (A1), F1.2, Q1.2
unnamed: D4.2 (A), R18.1
unnamed: D5.3 (BA), R21.1
unnamed: D5.2 (GA), R20.1
unnamed: D5.1 (RA), R19.1
unnamed: D6.3 (BA), R24.1
unnamed: D6.2 (GA), R23.1
unnamed: D6.1 (RA), R22.1
unnamed: F1.1, J1.1
unnamed: J3.2, R9.2, U3.94 (BOOT0)
unnamed: J4.10, R12.1
unnamed: J4.11, R11.1
unnamed: Q1.1, R1.2
unnamed: C5.2, U1.5 (BST)
unnamed: R4.1, R5.1, U1.6 (EN)
unnamed: R7.1, U1.8 (FB)
unnamed: C6.1, U1.7 (SS)
unnamed: C5.1, L1.2, U1.3 (SW)
unnamed: C22.1, U3.12 (PH0), U4.1
unnamed: C23.2, U3.13 (PH1), U4.3
unnamed: C19.1, U3.49 (VCAP_1)
unnamed: C20.1, U3.73 (VCAP_2)
unnamed: R10.2, U5.24 (RBIAS)
unnamed: C29.2, C30.2, U5.6 (VDDCR)
PG: R6.2, U1.1 (PG)
RCT: C32.2, FL3.2, J4.5 (RCT)
REF_CLK: U3.24 (PA1), U5.14 (~INT/REFCLKO)
RXD0: U3.33 (PC4), U5.8 (RXD0/MODE0)
RXD1: U3.34 (PC5), U5.7 (RXD1/MODE1)
RXN: D2.6, J4.6 (RD-), U5.22 (RXN)
RXP: D2.4, J4.3 (RD+), U5.23 (RXP)
SD_CARD_CD: J6.SWA (A), R17.2, U3.82 (PD1)
SD_CARD_CS: J6.2 (CD/DAT3), J9.1, R16.2, U3.81 (PD0)
SD_LED_B: R24.2, U3.88 (PD7)
SD_LED_G: R23.2, U3.87 (PD6)
SD_LED_R: R22.2, U3.86 (PD5)
SPI1_MISO: J6.7 (DAT0), J9.4, U3.31 (PA6)
SPI1_MOSI: J6.3 (CMD), J9.3, U3.91 (PB5)
SPI1_SCK: J6.5 (CLK), J9.2, U3.30 (PA5)
SWCLK: J2.3, U3.76 (PA14)
SWDIO: J2.4, U3.72 (PA13)
TCT: C31.2, FL2.2, J4.4 (TCT)
TXD0: U3.51 (PB12), U5.17 (TXD0)
TXD1: U3.52 (PB13), U5.18 (TXD1)
TXN: D2.3, J4.2 (TD-), U5.20 (TXN)
TXP: D2.1, J4.1 (TD+), U5.21 (TXP)
TX_EN: U3.48 (PB11), U5.16 (TXEN)
USART1_RX: J7.2, U3.69 (PA10), U6.1 (RO)
USART1_TX: J7.1, U3.68 (PA9), U6.4 (DI)
VREF+: C17.2, C18.2, FL1.2, U3.21 (VREF+), U3.22 (VDDA)
XTAL1: C24.1, U5.5 (XTAL1/CLKIN), Y1.1
XTAL2: C25.2, U5.4 (XTAL2), Y1.3

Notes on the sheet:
Ethernet Interface
MicroSD Storage
Power Supply
STM32 Core
RS485 / Modbus RTU
Status LEDs
Test Points

Board: 2 copper layers, 89 parts (0 on the bottom side), 69 nets, no tracks yet.

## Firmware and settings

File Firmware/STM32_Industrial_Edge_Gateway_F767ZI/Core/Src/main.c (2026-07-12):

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
/* Includes ------------------------------------------------------------------*/
#include "main.h"
#include "fatfs.h"
#include "lwip.h"

/* USER CODE BEGIN Includes */
#include "stm32f7xx_hal_def.h"
#include "stm32f7xx_hal_spi.h"
#include "string.h"
#include "stdio.h"
#include "time.h"
#include "lwip/apps/httpd.h"
/* USER CODE END Includes */

/* USER CODE BEGIN PTD */
typedef struct
{
  float temperature;
  float humidity;
  float pressure;
  float pm1;
  float pm25;
  float pm10;
  uint16_t aqi;

  uint32_t timestamp;
} AirData_t;

typedef struct
{
  float Clow;
  float Chigh;
  uint16_t Ilow;
  uint16_t Ihigh;
} AQITable;

typedef enum
{
  MODBUS_IDLE, // LED OFF
  MODBUS_BUSY, // Slow blink
  MODBUS_OK,   // Short flash
  MODBUS_ERROR // Solid ON
} ModbusStatus_t;

typedef enum
{
  SD_IDLE, // LED OFF
  SD_BUSY, // Slow blink
  SD_OK,   // Short flash
  SD_ERROR // Solid ON
} SDStatus_t;

typedef struct
{
  uint8_t rx[32];
  HAL_StatusTypeDef status;
} Modbus;
/* USER CODE END PTD */

/* USER CODE BEGIN PD */
#define SLAVE_ID 0x01
#define MODBUS_REQ_SIZE 8
#define FUN04_RESPONSE_SIZE 19
#define FUN03_RESPONSE_SIZE 9
#define PERIOD_MS 10000
/* USER CODE END PD */


SPI_HandleTypeDef hspi1;

UART_HandleTypeDef huart4;
UART_HandleTypeDef huart3;

/* USER CODE BEGIN PV */
AirData_t data = {0};
uint32_t lastSampleTick = 0;

uint8_t frameFun04[MODBUS_REQ_SIZE] = {
    SLAVE_ID,
    0x04,       // Function Code (3xxxx)
    0x00, 0x07, // Starting Address (30008)
    0x00, 0x07  // Number of Registers (30014)
};

uint8_t frameFun03[MODBUS_REQ_SIZE] = {
    SLAVE_ID,
    0x03,       // Function Code (4xxxx)
    0x00, 0x04, // Starting Address (40005)
    0x00, 0x02  // Number of Registers (40006)
};

static const AQITable PM25Table[] =
    {{0.0f, 9.0f, 0, 50},
     {9.1f, 35.4f, 51, 100},
     {35.5f, 55.4f, 101, 150},
     {55.5f, 125.4f, 151, 200},
     {125.5f, 225.4f, 201, 300},
     {225.5f, 325.4f, 301, 400},
     {325.5f, 500.4f, 401, 500}};

static const AQITable PM10Table[] =
    {{0, 54, 0, 50},
     {55, 154, 51, 100},
     {155, 254, 101, 150},
     {255, 354, 151, 200},
     {355, 424, 201, 300},
     {425, 504, 301, 400},
     {505, 604, 401, 500}};

FATFS fs;
FIL file;
FRESULT fr;
UINT bytesWritten;
UINT bytesRead;
/* USER CODE END PV */

void SystemClock_Config(void);
static void MPU_Config(void);
static void MX_GPIO_Init(void);
static void MX_UART4_Init(void);
static void MX_USART3_UART_Init(void);
static void MX_SPI1_Init(void);
/* USER CODE BEGIN 0 */
uint16_t Modbus_CRC16(uint8_t *buf, uint16_t len)
{
  uint16_t crc = 0xFFFF;

  for (uint16_t i = 0; i < len; i++)
  {
    crc ^= buf[i];

    for (uint8_t j = 0; j < 8; j++)
    {
      if (crc & 1)
        crc = (crc >> 1) ^ 0xA001;
      else
        crc >>= 1;
    }
  }

  return crc;
}

Modbus Modbus_TransmitReceive(UART_HandleTypeDef *huart, uint8_t *frame, uint8_t rxLength)
{
  Modbus result = {0};

  uint16_t crc = Modbus_CRC16(frame, MODBUS_REQ_SIZE - 2);

  uint8_t tx[8];
  memcpy(tx, frame, MODBUS_REQ_SIZE);

  tx[6] = crc & 0xFF;
  tx[7] = (crc >> 8) & 0xFF;

  result.status = HAL_UART_Transmit(huart, tx, MODBUS_REQ_SIZE, 1000);

  if (result.status != HAL_OK)
    return result;

  result.status = HAL_UART_Receive(huart, result.rx, rxLength, 1000);

  if (result.status != HAL_OK)
    return result;

  uint16_t rxCRC = result.rx[rxLength - 2] | (result.rx[rxLength - 1] << 8);
  uint16_t calcCRC = Modbus_CRC16(result.rx, rxLength - 2);

  if (rxCRC != calcCRC)
    result.status = HAL_ERROR;

  return result;
}

uint16_t AQIFromTable(float concentration,
                      const AQITable *table,
                      uint8_t size)
{
  if (concentration < 0)
    return 0;

  for (int i = 0; i < size; i++)
  {
    if (concentration >= table[i].Clow &&
        concentration <= table[i].Chigh)
    {
      float aqi =
          ((table[i].Ihigh - table[i].Ilow) /
           (table[i].Chigh - table[i].Clow)) *
              (concentration - table[i].Clow) +
          table[i].Ilow;

      return (uint16_t)(aqi + 0.5f);
    }
  }

  return 500;
}

uint16_t CalculateAQI(float pm25, float pm10)
{
  uint16_t aqi25 =
      AQIFromTable(pm25,
                   PM25Table,
                   sizeof(PM25Table) / sizeof(AQITable));

  uint16_t aqi10 =
      AQIFromTable(pm10,
                   PM10Table,
                   sizeof(PM10Table) / sizeof(AQITable));

  return (aqi25 > aqi10) ? aqi25 : aqi10;
}

void ModbusStatusLED(ModbusStatus_t modbusStatus)
{
  static uint32_t lastToggle = 0;

  switch (modbusStatus)
  {
  case MODBUS_IDLE:
    HAL_GPIO_WritePin(GPIOA, GPIO_PIN_3, GPIO_PIN_RESET);
    break;

  case MODBUS_BUSY:
    if (HAL_GetTick() - lastToggle >= 500)
    {
      lastToggle = HAL_GetTick();
      HAL_GPIO_TogglePin(GPIOA, GPIO_PIN_3);
    }
    break;

  case MODBUS_OK:
    HAL_GPIO_WritePin(GPIOA, GPIO_PIN_3, GPIO_PIN_SET);
    HAL_Delay(100);
    HAL_GPIO_WritePin(GPIOA, GPIO_PIN_3, GPIO_PIN_RESET);
    break;

  case MODBUS_ERROR:
    HAL_GPIO_WritePin(GPIOA, GPIO_PIN_3, GPIO_PIN_SET);
    break;
  }
}

void SDStatusLED(SDStatus_t sdStatus)
{
  static uint32_t lastToggle = 0;

  switch (sdStatus)
  {
  case SD_IDLE:
    HAL_GPIO_WritePin(GPIOC, GPIO_PIN_0, GPIO_PIN_RESET);
    break;

  case SD_BUSY:
    if (HAL_GetTick() - lastToggle >= 500)
    {
      lastToggle = HAL_GetTick();
      HAL_GPIO_TogglePin(GPIOC, GPIO_PIN_0);
    }
    break;

  case SD_OK:
    HAL_GPIO_WritePin(GPIOC, GPIO_PIN_0, GPIO_PIN_SET);
    HAL_Delay(100);
    HAL_GPIO_WritePin(GPIOC, GPIO_PIN_0, GPIO_PIN_RESET);
    break;

  case SD_ERROR:
    HAL_GPIO_WritePin(GPIOC, GPIO_PIN_0, GPIO_PIN_SET);
    break;
  }
}

u16_t SSI_Handler(int iIndex, char *pcInsert, int iInsertLen)
{
  extern uint32_t lastSampleTick;

  switch (iIndex)
  {
  case 0:
    return snprintf(pcInsert, iInsertLen, "%.1f", data.pm25);

  case 1:
    return snprintf(pcInsert, iInsertLen, "%.1f", data.pm10);

  case 2:
    return snprintf(pcInsert, iInsertLen, "%.1f", data.pm1);

  case 3:
    return snprintf(pcInsert, iInsertLen, "%.2f", data.temperature);

  case 4:
    return snprintf(pcInsert, iInsertLen, "%.2f", data.humidity);

  case 5:
    return snprintf(pcInsert, iInsertLen, "%.1f", data.pressure);

  case 6:
    return snprintf(pcInsert, iInsertLen, "%u", data.aqi);

  case 7:
    return snprintf(pcInsert, iInsertLen, "%lu", (HAL_GetTick() - lastSampleTick) / 1000);

  default:
    pcInsert[0] = '\0';
    return 0;
  }
}
/* USER CODE END 0 */

/**
 * @brief  The application entry point.
 * @retval int
 */
int main(void)
{

  /* USER CODE BEGIN 1 */
  ModbusStatus_t modbusStatus = MODBUS_IDLE;

  SDStatus_t sdStatus = SD_IDLE;
  /* USER CODE END 1 */

  /* MPU Configuration--------------------------------------------------------*/
  MPU_Config();

  /* MCU Configuration--------------------------------------------------------*/

  /* Reset of all peripherals, Initializes the Flash interface and the Systick. */
  HAL_Init();

  /* Configure the system clock */
  SystemClock_Config();

  /* Initialize all configured peripherals */
  MX_GPIO_Init();
  MX_UART4_Init();
  MX_USART3_UART_Init();
  MX_SPI1_Init();
  MX_FATFS_Init();
  MX_LWIP_Init();
  /* USER CODE BEGIN 2 */
  fr = f_mount(&fs, "", 1);
  if (fr != FR_OK)
  {
    sdStatus = SD_ERROR;
    SDStatusLED(sdStatus);
  }

  httpd_init();

  const char *tags[] = {
      "pm25", "pm10", "pm1",
      "temp", "hum", "press",
      "aqi", "updated"};

  http_set_ssi_handler(SSI_Handler, tags, LWIP_ARRAYSIZE(tags));
  /* USER CODE END 2 */

  /* Infinite loop */
  /* USER CODE BEGIN WHILE */
  uint32_t lastSample = 0;

  while (1)
  {
    MX_LWIP_Process();

    if (HAL_GetTick() - lastSample >= PERIOD_MS)
    {
      lastSample = HAL_GetTick();
      modbusStatus = MODBUS_BUSY;
      ModbusStatusLED(modbusStatus);
      Modbus modbusFun04 = Modbus_TransmitReceive(&huart4, frameFun04, FUN04_RESPONSE_SIZE);
      Modbus modbusFun03 = Modbus_TransmitReceive(&huart4, frameFun03, FUN03_RESPONSE_SIZE);

      if (modbusFun04.status != HAL_OK || modbusFun03.status != HAL_OK)
      {
        modbusStatus = MODBUS_ERROR;
        ModbusStatusLED(modbusStatus);
        continue;
      }

      uint8_t *rxFun04 = modbusFun04.rx;
      uint8_t *rxFun03 = modbusFun03.rx;

      if ((rxFun04[0] != SLAVE_ID || rxFun04[1] != 0x04 || rxFun04[2] != 14) ||
          (rxFun03[0] != SLAVE_ID || rxFun03[1] != 0x03 || rxFun03[2] != 4))
      {
        modbusStatus = MODBUS_ERROR;
        ModbusStatusLED(modbusStatus);
        HAL_Delay(PERIOD_MS);
        continue;
      }

      data.temperature = (((uint16_t)rxFun04[3] << 8) | rxFun04[4]) * 0.01f;
      data.humidity = (((uint16_t)rxFun04[5] << 8) | rxFun04[6]) * 0.01f;
      data.pressure = (((uint16_t)rxFun04[9] << 8) | rxFun04[10]) * 0.1f;
      data.pm1 = (((uint16_t)rxFun04[11] << 8) | rxFun04[12]) * 0.1f;
      data.pm25 = (((uint16_t)rxFun04[13] << 8) | rxFun04[14]) * 0.1f;
      data.pm10 = (((uint16_t)rxFun04[15] << 8) | rxFun04[16]) * 0.1f;
      data.aqi = CalculateAQI(data.pm25, data.pm10);

      data.timestamp =
          ((uint32_t)(((uint16_t)rxFun03[3] << 8) | rxFun03[4]) << 16) |
          (((uint16_t)rxFun03[5] << 8) | rxFun03[6]);

      lastSampleTick = HAL_GetTick();

      time_t t = (time_t)(data.timestamp + 3 * 3600); // UTC+3
      struct tm *tm_info = gmtime(&t);

      char timeStr[32];

      strftime(timeStr, sizeof(timeStr), "%Y-%m-%d %H:%M:%S", tm_info);

      modbusStatus = MODBUS_OK;
      ModbusStatusLED(modbusStatus);

      sdStatus = SD_BUSY;
      SDStatusLED(sdStatus);

      FILINFO fno;
      fr = f_stat("data.csv", &fno);

      if (fr == FR_NO_FILE)
      {
        fr = f_open(&file, "data.csv", FA_CREATE_NEW | FA_WRITE);

        if (fr == FR_OK)
        {
          char header[] = "Timestamp,Temperature,Humidity,Pressure,PM1,PM2.5,PM10,AQI\r\n";

          f_write(&file, header, strlen(header), &bytesWritten);
          f_close(&file);
        }
      }

      fr = f_open(&file, "data.csv", FA_OPEN_EXISTING | FA_WRITE);

      if (fr != FR_OK)
      {
        sdStatus = SD_ERROR;
        SDStatusLED(sdStatus);
        continue;
      }

      char fdata[128];
      sprintf(fdata,
              "%s,%.2f,%.2f,%.1f,%.1f,%.1f,%.1f,%u\r\n",
              timeStr,
              data.temperature,
              data.humidity,
              data.pressure,
              data.pm1,
              data.pm25,
              data.pm10,
              data.aqi);

      fr = f_write(&file, fdata, strlen(fdata), &bytesWritten);

      if (fr != FR_OK || bytesWritten != strlen(fdata))
      {
        sdStatus = SD_ERROR;
        SDStatusLED(sdStatus);
        continue;
      }

      f_sync(&file);
      f_close(&file);
      sdStatus = SD_OK;
      SDStatusLED(sdStatus);
    }
    /* USER CODE END WHILE */

    /* USER CODE BEGIN 3 */
  }
  /* USER CODE END 3 */
}

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
/* MPU Configuration */

void MPU_Config(void)
{
  MPU_Region_InitTypeDef MPU_InitStruct = {0};

  /* Disables the MPU */
  HAL_MPU_Disable();

  /** Initializes and configures the Region and the memory to be protected
   */
  MPU_InitStruct.Enable = MPU_REGION_ENABLE;
  MPU_InitStruct.Number = MPU_REGION_NUMBER0;
  MPU_InitStruct.BaseAddress = 0x0;
  MPU_InitStruct.Size = MPU_REGION_SIZE_4GB;
  MPU_InitStruct.SubRegionDisable = 0x87;
  MPU_InitStruct.TypeExtField = MPU_TEX_LEVEL0;
  MPU_InitStruct.AccessPermission = MPU_REGION_NO_ACCESS;
  MPU_InitStruct.DisableExec = MPU_INSTRUCTION_ACCESS_DISABLE;
  MPU_InitStruct.IsShareable = MPU_ACCESS_SHAREABLE;
  MPU_InitStruct.IsCacheable = MPU_ACCESS_NOT_CACHEABLE;
  MPU_InitStruct.IsBufferable = MPU_ACCESS_NOT_BUFFERABLE;

  HAL_MPU_ConfigRegion(&MPU_InitStruct);
  /* Enables the MPU */
  HAL_MPU_Enable(MPU_PRIVILEGED_DEFAULT);
}

/**
 * @brief  This function is executed in case of error occurrence.
 * @retval None
 */
void Error_Handler(void)
{
  /* USER CODE BEGIN Error_Handler_Debug */
  /* User can add his own implementation to report the HAL error return state */
  __disable_irq();
  while (1)
  {
  }
  /* USER CODE END Error_Handler_Debug */
}
#ifdef USE_FULL_ASSERT
/**
 * @brief  Reports the name of the source file and the source line number
 *         where the assert_param error has occurred.
 * @param  file: pointer to the source file name
 * @param  line: assert_param error line source number
 * @retval None
 */
void assert_failed(uint8_t *file, uint32_t line)
{
  /* USER CODE BEGIN 6 */
  /* User can add his own implementation to report the file name and line number,
     ex: printf("Wrong parameters value: file %s on line %d\r\n", file, line) */
  /* USER CODE END 6 */
}
#endif /* USE_FULL_ASSERT */

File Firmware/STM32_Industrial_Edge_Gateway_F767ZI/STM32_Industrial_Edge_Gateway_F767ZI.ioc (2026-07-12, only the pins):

Mcu.UserName=STM32F767ZITx
PA1.Signal=ETH_REF_CLK
PA13.Signal=SYS_JTMS-SWDIO
PA14.Signal=SYS_JTCK-SWCLK
PA2.Signal=ETH_MDIO
PA3.Signal=GPIO_Output
PA5.Signal=SPI1_SCK
PA6.Signal=SPI1_MISO
PA7.Signal=ETH_CRS_DV
PB13.Signal=ETH_TXD1
PC0.Signal=GPIO_Output
PC1.Signal=ETH_MDC
PC4.Signal=ETH_RXD0
PC5.Signal=ETH_RXD1
PD0.Signal=UART4_RX
PD1.Signal=UART4_TX
PD7.Signal=SPI1_MOSI
PD8.Signal=USART3_TX
PD9.Signal=USART3_RX
PF10.Signal=GPIO_Output
PF5.Signal=GPIO_Output
PG11.Signal=ETH_TX_EN
PG13.Signal=ETH_TXD0
PH0/OSC_IN.Signal=RCC_OSC_IN
PH1/OSC_OUT.Signal=RCC_OSC_OUT

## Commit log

2026-07-12 Complete prototype implementation
    [EXAMPLE_DATA.CSV]
2026-07-13 Remove "Documentation" folder
    [EXAMPLE_DATA.CSV]
2026-07-14 Power Schematic
    [STM32_Industrial_Edge_Gateway_v0.2.0.kicad_pcb, STM32_Industrial_Edge_Gateway_v0.2.0.kicad_sch]
2026-07-14 STM32 MCU Core Schematic
    [STM32_Industrial_Edge_Gateway_v0.2.0.kicad_sch]
2026-07-15 Complete schematic
    [STM32_Industrial_Edge_Gateway_v0.2.0.kicad_sch]
2026-07-15 Update Ethernet Interface schematic
    [STM32_Industrial_Edge_Gateway_v0.2.0.kicad_sch]
2026-07-17 Remove "Hardware" folder
    [STM32_Industrial_Edge_Gateway_v0.2.0.kicad_pcb, STM32_Industrial_Edge_Gateway_v0.2.0.kicad_sch]
2026-07-17 Update schematic
    [STM32_Industrial_Edge_Gateway_v0.2.0.csv, STM32_Industrial_Edge_Gateway_v0.2.0.kicad_sch]
2026-07-18 Complete Testing Points and Status LEDs schematics
    [STM32_Industrial_Edge_Gateway_v0.2.0.kicad_sch]
2026-07-18 Fix and update schematic
    [STM32_Industrial_Edge_Gateway_v0.2.0.csv, STM32_Industrial_Edge_Gateway_v0.2.0.kicad_pcb, STM32_Industrial_Edge_Gateway_v0.2.0.kicad_sch]

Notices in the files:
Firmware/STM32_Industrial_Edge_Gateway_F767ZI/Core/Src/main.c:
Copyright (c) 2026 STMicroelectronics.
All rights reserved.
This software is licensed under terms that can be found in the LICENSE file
